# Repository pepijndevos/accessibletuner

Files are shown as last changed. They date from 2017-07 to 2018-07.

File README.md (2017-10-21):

# accessibletuner
Accessible Guitar Tuner

[Project page](https://hackaday.io/project/26255-accesible-guitar-tuner)

## Bountysource



Please get in touch if you want to help. I may be able to send you a PCB, put up additional bounties or make other arrangements.

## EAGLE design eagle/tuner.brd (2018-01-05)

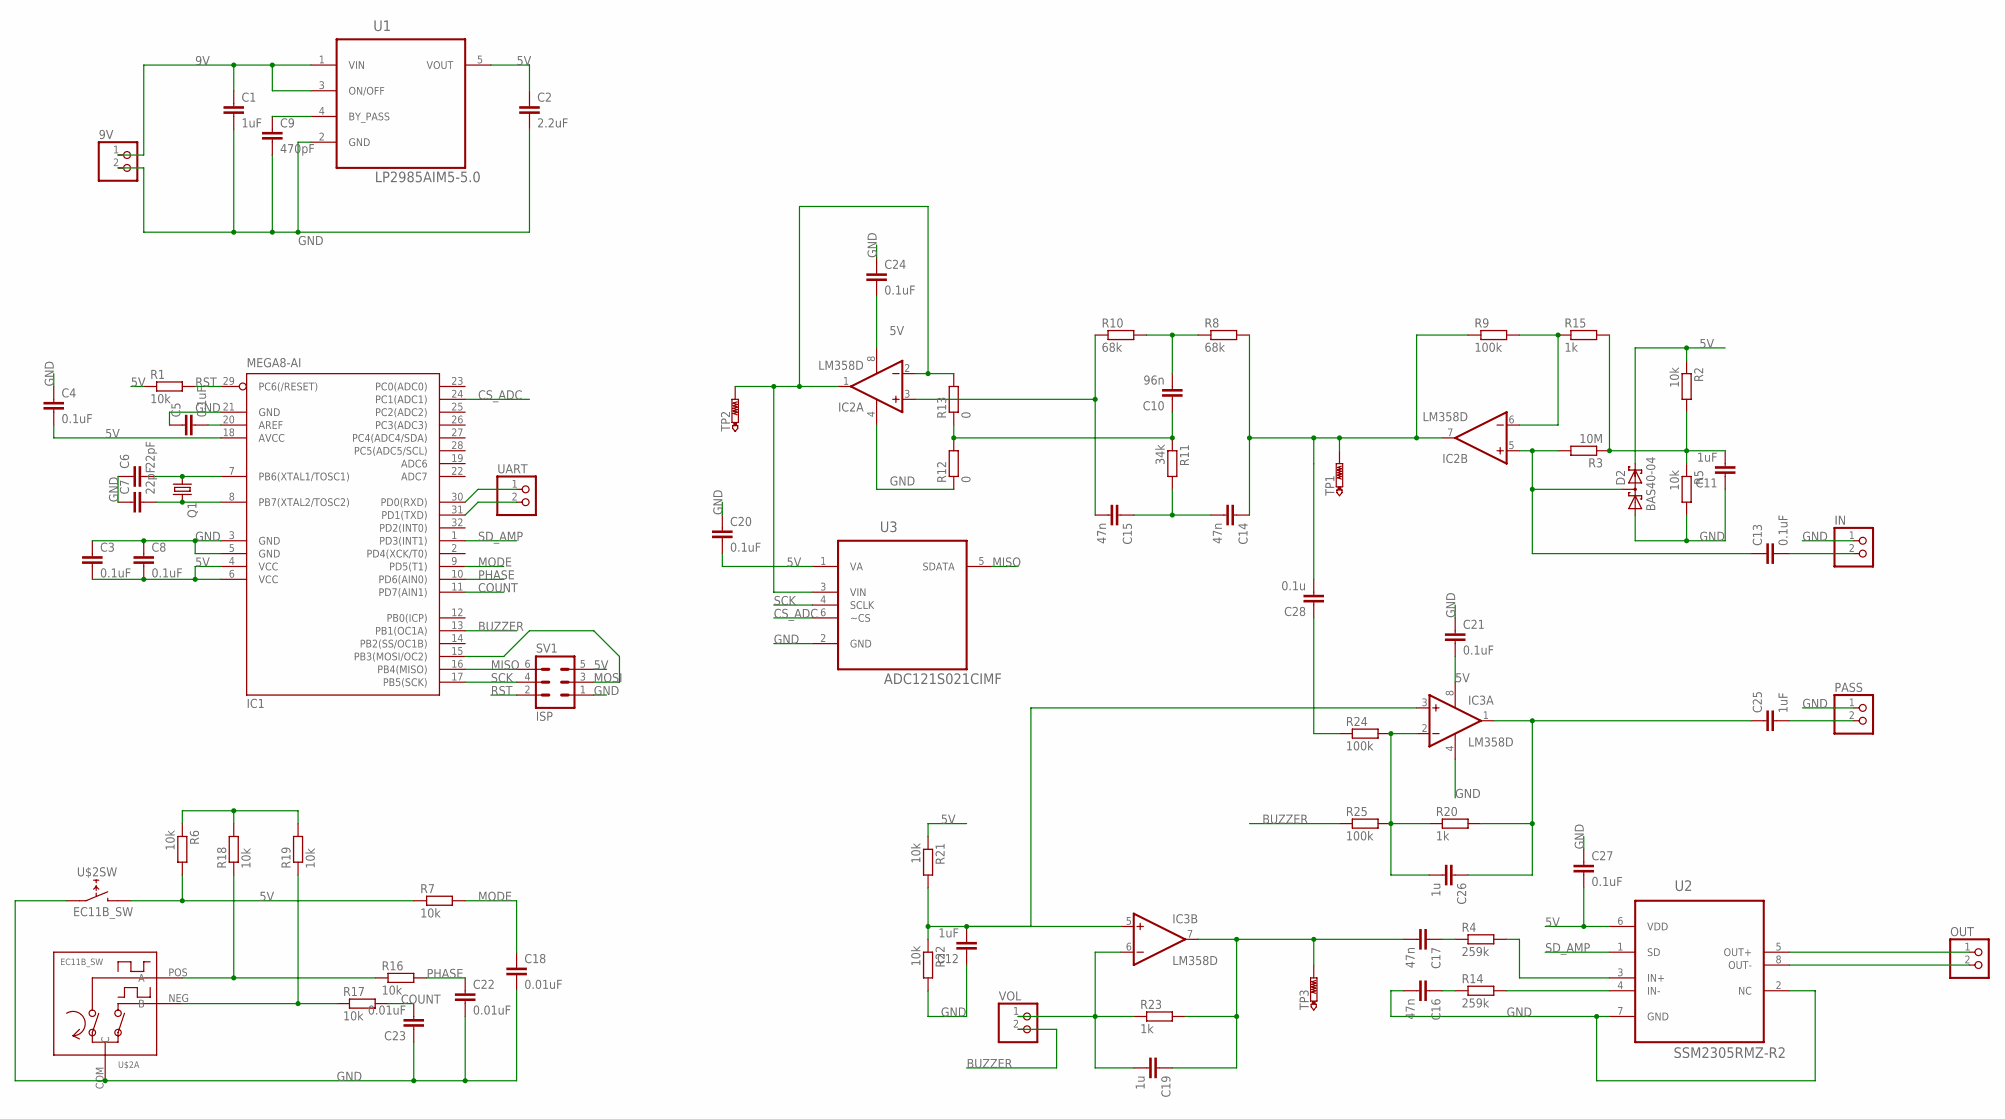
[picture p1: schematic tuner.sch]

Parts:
9V: PINHD-1X2; 1X02
C1, C11, C12, C25: 1uF; C0805
C2: 2.2uF; C0805
C3, C4, C5, C8, C13, C20, C21, C24, C27: 0.1uF; C0805
C6, C7: 22pF; C0805
C9: 470pF; C0805
C10: 96n; C0805
C14, C15, C16, C17: 47n; C0805
C18, C22, C23: 0.01uF; C0805
C19, C26: 1u; C0805
C28: 0.1u; C0805
D2: BAS40-04; SOT23
IC1: MEGA8-AI; TQFP32-08
IC2, IC3: LM358D; SO08
IN: PINHD-1X2; 1X02
OUT: PINHD-1X2; 1X02
PASS: PINHD-1X2; 1X02
Q1: CRYSTALHC49S; HC49/S
R1, R2, R5, R6, R7, R16, R17, R18, R19, R21, R22: 10k; M0805
R3: 10M; M0805
R4, R14: 259k; M0805
R8, R10: 68k; M0805
R9, R24, R25: 100k; M0805
R11: 34k; M0805
R12, R13: 0; M0805
R15, R20, R23: 1k; M0805
SV1: ISP; MA03-2
TP1, TP2, TP3: PTR1B1,27; B1,27
U1: LP2985AIM5-5.0; SOT95P284X119-5N
U2: SSM2305RMZ-R2; SOP65P490X110-8N
U3: ADC121S021CIMF; SOT95P284X122-6N
U$2: EC11B_SW; EC11B
UART: PINHD-1X2; 1X02
VOL: PINHD-1X2; 1X02

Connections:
5V: C2.1, C3.2, C4.2, C8.2, C20.2, C21.2, C24.2, C27.2, D2.2 (C2), IC1.4 (VCC), IC1.6 (VCC), IC1.18 (AVCC), IC2.8 (V+), IC3.8 (V+), R1.1, R2.1, R6.1, R18.2, R19.2, R21.1, SV1.5, U1.5 (VOUT), U2.6 (VDD), U3.1 (VA)
9V: 9V.1, C1.1, U1.1 (VIN), U1.3 (ON/OFF)
BUZZER: IC1.13 (PB1(OC1A)), R25.1, VOL.2
COUNT: C23.2, IC1.11 (PD7(AIN1)), R17.2
CS_ADC: IC1.24 (PC1(ADC1)), U3.6 (~CS)
FG: C10.1, R11.1, R12.2, R13.1
GND: 9V.2, C1.2, C2.2, C3.1, C4.1, C5.1, C6.1, C7.1, C8.1, C9.2, C11.1, C12.1, C16.2, C18.2, C20.1, C21.1, C22.2, C23.1, C24.1, C27.1, D2.1 (A1), IC1.3 (GND), IC1.5 (GND), IC1.21 (GND), IC2.4 (V-), IC3.4 (V-), IN.1, PASS.1, R5.2, R12.1, R22.2, SV1.1, U1.2 (GND), U2.2 (NC), U2.7 (GND), U3.2 (GND), U$2.COM (C), U$2.SW1 (D)
MISO: IC1.16 (PB4(MISO)), SV1.6, U3.5 (SDATA)
MODE: C18.1, IC1.9 (PD5(T1)), R7.2
MOSI: IC1.15 (PB3(MOSI/OC2)), SV1.3
unnamed: C28.1, R24.1
unnamed: C9.1, U1.4 (BY_PASS)
unnamed: C5.2, IC1.20 (AREF)
unnamed: C6.2, IC1.7 (PB6(XTAL1/TOSC1)), Q1.1
unnamed: C7.2, IC1.8 (PB7(XTAL2/TOSC2)), Q1.2
unnamed: C17.2, C19.1, IC3.7 (OUT), R23.2, TP3.TP
unnamed: C19.2, IC3.6 (-IN), R23.1, VOL.1
unnamed: C12.2, IC3.3 (+IN), IC3.5 (+IN), R21.2, R22.1
unnamed: OUT.1, U2.5 (OUT+)
unnamed: C14.1, C28.2, IC2.7 (OUT), R8.2, R9.1, TP1.TP
unnamed: OUT.2, U2.8 (OUT-)
unnamed: C13.2, IN.2
unnamed: IC2.6 (-IN), R9.2, R15.1
unnamed: R4.2, U2.3 (IN+)
unnamed: C25.2, PASS.2
unnamed: C13.1, D2.3 (C1A2), IC2.5 (+IN), R3.2
unnamed: C11.2, R2.2, R3.1, R5.1, R15.2
unnamed: C25.1, C26.1, IC3.1 (OUT), R20.2
unnamed: C14.2, C15.1, R11.2
unnamed: C15.2, IC2.3 (+IN), R10.1
unnamed: R14.2, U2.4 (IN-)
unnamed: R16.1, R18.1, U$2.POS (A)
unnamed: R17.1, R19.1, U$2.NEG (B)
unnamed: IC1.30 (PD0(RXD)), UART.1
unnamed: C10.2, R8.1, R10.2
unnamed: IC1.31 (PD1(TXD)), UART.2
unnamed: C16.1, R14.1
unnamed: IC2.1 (OUT), IC2.2 (-IN), R13.2, TP2.TP, U3.3 (VIN)
unnamed: C17.1, R4.1
unnamed: C26.2, IC3.2 (-IN), R20.1, R24.2, R25.2
unnamed: R6.2, R7.1, U$2.SW2 (E)
PHASE: C22.1, IC1.10 (PD6(AIN0)), R16.2
RST: IC1.29 (PC6(/RESET)), R1.2, SV1.2
SCK: IC1.17 (PB5(SCK)), SV1.4, U3.4 (SCLK)
SD_AMP: IC1.1 (PD3(INT1)), U2.1 (SD)

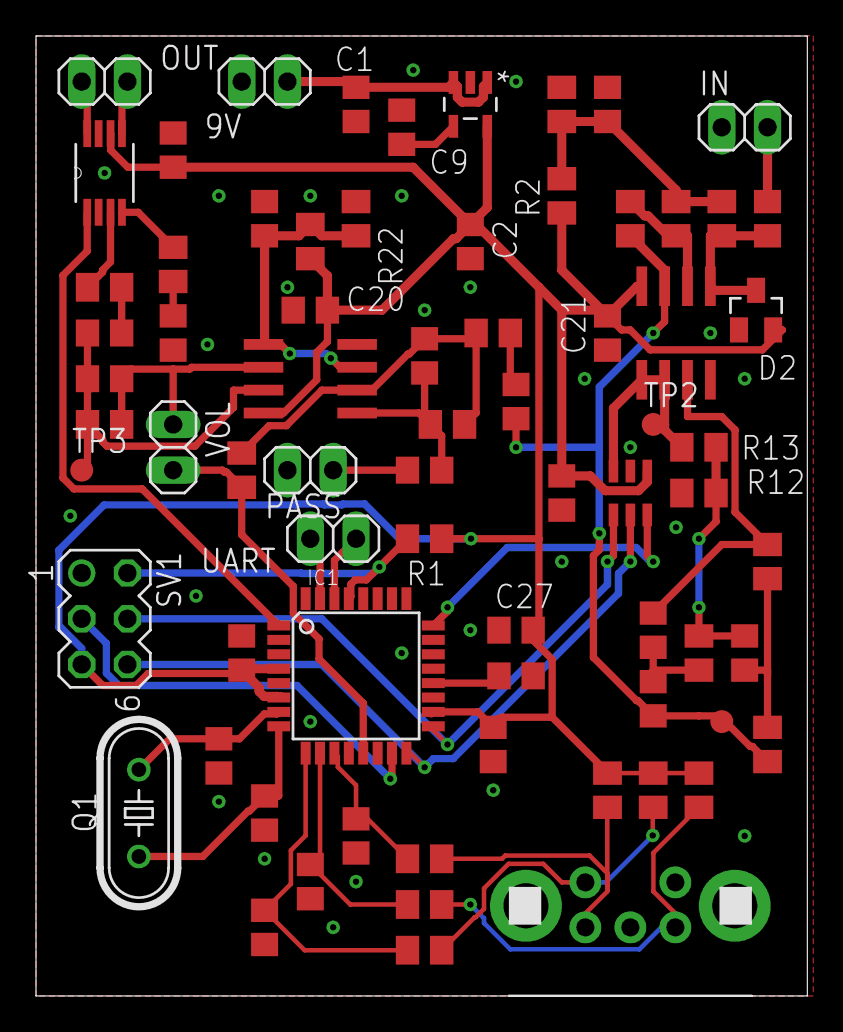
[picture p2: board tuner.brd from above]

Board: 2 copper layers, 42.8 x 53.3 mm, 72 parts (0 on the bottom side), 45 nets.

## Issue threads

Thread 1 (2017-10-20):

Seperate analog and digital circuitry

pepijndevos, 2017-10-20:
In the current PCB revision analog and digital ground and power supply are not really properly isolated. I added the inductor to AVCC of the AVR because the datasheet told me to, but the rest is a bit of a mess.

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

pepijndevos, 2017-11-27:
A new circuit was proposed by @brain4d, which is being implemented.

Closed 2017-11-27.

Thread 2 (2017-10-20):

Implement software band-pass filter

pepijndevos, 2017-10-20:
This will increase the reliability of tuning hopefully, but requires a lot of changes to the code.
The sampling frequency needs to be decreased to reasonable values to be able to construct reasonable filters.
The code also needs to be converted to using signed integers throughout.
Some work has been done in this area, but nothing that really works.

Ideally the filter is dynamically adjusted to the right frequency, but a lookup table is acceptable I think.

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

brain4d, 2017-10-24:
i'm really interested  in your  bounty. I have some experience in mixed-signal pcb design, and firmware development.
How can i discuss with you in detail?

pepijndevos, 2017-10-24:
Awesome! Shoot me an email at pepijndevos@gmail.com

brain4d, 2017-10-24:
i already sent you an email.

pepijndevos, 2018-02-22:
As of dbe5d09517160fcf41d7a1f8d89856c811fa1d5f this has been implemented by me. So instead I'll award the bounty to @ant0nisk for his work on the 3D printed case.

Closed 2018-02-22.

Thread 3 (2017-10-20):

Improve input stage

pepijndevos, 2017-10-20:
- [x] high input impedance
- [ ] automatic gain control
- [x] filter (50Hz) interference
- [x] stable

Closed 2018-02-08.

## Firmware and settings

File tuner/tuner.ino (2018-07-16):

#include <SPI.h>

#include "trig8.h"
#include "iir.h"
#include <limits.h>

#define SEMI 1.059463
#define CENT 1.0005777895

// Adjust to tune the tuner
#define ADCFREQ 1982.0
// scales to the range of sin8: 0-255
#define OMEGA (256/ADCFREQ)

#define E4 329.63
#define B3 246.94
#define G3 196.00
#define D3 146.83
#define A2 110.00
#define E2 82.41

#define BUZZER 9
#define EN_OUT 3
#define ADC_CS A1

// PORTB
#define SCROLL_MODE 5
#define SCROLL_PHASE 6
#define SCROLL_COUNTER 7

volatile unsigned long long counter = 0;
unsigned long sample_interval = 0;
unsigned long click_interval = 0;
int phase = 0;

const float strings[6] = {E2, A2, D3, G3, B3, E4};
int note_idx = 0;
bool standard_tuning = true;
float note = strings[0]*OMEGA;
IIR_filter bpf = iirpeak(strings[0]*2/ADCFREQ, 10*2/ADCFREQ);
IIR_filter lpf = {0, 0, 0, 0, 2, 4, 2, 3910, -1870};

void setup(){
  Serial.begin(250000);
  SPI.begin();
  
  pinMode(ADC_CS, OUTPUT);
  pinMode(BUZZER, OUTPUT);
  pinMode(EN_OUT, OUTPUT);
    // rotary encoder
  pinMode(SCROLL_MODE, INPUT);
  pinMode(SCROLL_PHASE, INPUT);
  pinMode(SCROLL_COUNTER, INPUT);

  PCICR = (1 << PCIE2);  //Enable PCI2 interupt
  PCMSK2 = (1 << PCINT21) | (1 << PCINT22) | (1 << PCINT23);  // Mask for encoder pins
      
  // Enable output A, B, fast PWM
  TCCR1A =  _BV(COM1A1) | _BV(WGM10);
  // No PWM prescaler
  TCCR1B = _BV(CS10) | _BV(WGM12);
  // Duty cycle
  OCR1A = 127;
  digitalWrite(EN_OUT, HIGH);
}

//https://www.circuitsathome.com/mcu/reading-rotary-encoder-on-arduino/
SIGNAL(PCINT2_vect) {
  const int8_t enc_states[] = {0,-1,1,0,1,0,0,-1,-1,0,0,1,0,1,-1,0};
  // 00 00 -> --
  // 00 01 -> CW
  // 00 10 -> CCW
  // 00 11 -> --
  // 01 00 -> CCW
  // 01 01 -> --
  // 01 10 -> --
  // 01 11 -> CW
  // 10 00 -> CW
  // 10 01 -> --
  // 10 10 -> --
  // 10 11 -> CCW
  // 11 00 -> --
  // 11 01 -> CCW
  // 11 10 -> CW
  // 11 11 -> --
  //const float enc_states[] = {1,1,1,1,1,1,1,1/SEMI,1,1,1,SEMI,1,1,1,1};
  static uint8_t old_AB = 0;

  old_AB <<= 2; //remember previous state
  old_AB |= (PIND >> 6) & 0x03; //add current state
  //note_idx *= enc_states[old_AB & 0x0f];
  note_idx += enc_states[old_AB & 0x0f];

  if(((PIND >> 5) & 0x01)==0) {
    standard_tuning = !standard_tuning;
    note_idx = 0;
  }

  float string_freq;
  if(standard_tuning) {
    string_freq = strings[(((note_idx/4) % 6) + 6) % 6];
  } else {
    string_freq = strings[0]*pow(SEMI, note_idx);
  }
  
  note = string_freq*OMEGA;
  IIR_filter bpf = iirpeak(string_freq*2/ADCFREQ, 10*2/ADCFREQ);
}

void loop() {
  while(micros()-sample_interval < 500 || micros() < sample_interval);
  sample_interval = micros();

  // Do this first to reduce jitter
  OCR1A = sin8(note*counter+phase);

  SPI.beginTransaction(SPISettings(F_CPU/2, MSBFIRST, SPI_MODE0));
  digitalWrite(ADC_CS, LOW);
  delayMicroseconds(1);
  int16_t val = (int16_t)SPI.transfer16(0) - (1<<11);
  digitalWrite(ADC_CS, HIGH);
  SPI.endTransaction();
    
  int16_t sine = (int16_t)sin8(note*counter)-(int16_t)127;

  int16_t fval = IIR2(&bpf, val);
  int16_t prod = fval*sine;
  int16_t lpval = IIR2(&lpf, prod);
  // timeout on clicker for anti-madness
  if(millis()-click_interval > 20) {
    click_interval = millis();
    phase = (lpval>0)*128;
  }

//if(counter % 64 == 0) {
//  Serial.print(((PIND >> 5) & 0x01)==0);
//  Serial.print("\t");
//  Serial.print(note_idx, DEC);
//  Serial.print("\t");
//  Serial.println(standard_tuning, DEC);
//  Serial.print("\t");
//  Serial.println(micros()-sample_interval, DEC);
//}

  counter++;
}

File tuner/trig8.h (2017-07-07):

#ifndef __INC_LIB8TION_TRIG_H
#define __INC_LIB8TION_TRIG_H

#define LIB8STATIC __attribute__ ((unused)) static

///@ingroup lib8tion

///@defgroup Trig Fast trig functions
/// Fast 8 and 16-bit approximations of sin(x) and cos(x).
///        Don't use these approximations for calculating the
///        trajectory of a rocket to Mars, but they're great
///        for art projects and LED displays.
///
///        On Arduino/AVR, the 16-bit approximation is more than
///        10X faster than floating point sin(x) and cos(x), while
/// the 8-bit approximation is more than 20X faster.
///@{

#if defined(__AVR__)
#define sin16 sin16_avr
#else
#define sin16 sin16_C
#endif

/// Fast 16-bit approximation of sin(x). This approximation never varies more than
/// 0.69% from the floating point value you'd get by doing
///
///     float s = sin(x) * 32767.0;
///
/// @param theta input angle from 0-65535
/// @returns sin of theta, value between -32767 to 32767.
LIB8STATIC int16_t sin16_avr( uint16_t theta )
{
    static const uint8_t data[] =
    { 0,         0,         49, 0, 6393%256,   6393/256, 48, 0,
      12539%256, 12539/256, 44, 0, 18204%256, 18204/256, 38, 0,
      23170%256, 23170/256, 31, 0, 27245%256, 27245/256, 23, 0,
      30273%256, 30273/256, 14, 0, 32137%256, 32137/256,  4 /*,0*/ };

    uint16_t offset = (theta & 0x3FFF);

    // AVR doesn't have a multi-bit shift instruction,
    // so if we say "offset >>= 3", gcc makes a tiny loop.
    // Inserting empty volatile statements between each
    // bit shift forces gcc to unroll the loop.
    offset >>= 1; // 0..8191
    asm volatile("");
    offset >>= 1; // 0..4095
    asm volatile("");
    offset >>= 1; // 0..2047

    if( theta & 0x4000 ) offset = 2047 - offset;

    uint8_t sectionX4;
    sectionX4 = offset / 256;
    sectionX4 *= 4;

    uint8_t m;

    union {
        uint16_t b;
        struct {
            uint8_t blo;
            uint8_t bhi;
        };
    } u;

    //in effect u.b = blo + (256 * bhi);
    u.blo = data[ sectionX4 ];
    u.bhi = data[ sectionX4 + 1];
    m     = data[ sectionX4 + 2];

    uint8_t secoffset8 = (uint8_t)(offset) / 2;

    uint16_t mx = m * secoffset8;

    int16_t  y  = mx + u.b;
    if( theta & 0x8000 ) y = -y;

    return y;
}

/// Fast 16-bit approximation of sin(x). This approximation never varies more than
/// 0.69% from the floating point value you'd get by doing
///
///     float s = sin(x) * 32767.0;
///
/// @param theta input angle from 0-65535
/// @returns sin of theta, value between -32767 to 32767.
LIB8STATIC int16_t sin16_C( uint16_t theta )
{
    static const uint16_t base[] =
    { 0, 6393, 12539, 18204, 23170, 27245, 30273, 32137 };
    static const uint8_t slope[] =
    { 49, 48, 44, 38, 31, 23, 14, 4 };

    uint16_t offset = (theta & 0x3FFF) >> 3; // 0..2047
    if( theta & 0x4000 ) offset = 2047 - offset;

    uint8_t section = offset / 256; // 0..7
    uint16_t b   = base[section];
    uint8_t  m   = slope[section];

    uint8_t secoffset8 = (uint8_t)(offset) / 2;

    uint16_t mx = m * secoffset8;
    int16_t  y  = mx + b;

    if( theta & 0x8000 ) y = -y;

    return y;
}


/// Fast 16-bit approximation of cos(x). This approximation never varies more than
/// 0.69% from the floating point value you'd get by doing
///
///     float s = cos(x) * 32767.0;
///
/// @param theta input angle from 0-65535
/// @returns sin of theta, value between -32767 to 32767.
LIB8STATIC int16_t cos16( uint16_t theta)
{
    return sin16( theta + 16384);
}

///////////////////////////////////////////////////////////////////////

// sin8 & cos8
//        Fast 8-bit approximations of sin(x) & cos(x).
//        Input angle is an unsigned int from 0-255.
//        Output is an unsigned int from 0 to 255.
//
//        This approximation can vary to to 2%
//        from the floating point value you'd get by doing
//          float s = (sin( x ) * 128.0) + 128;
//
//        Don't use this approximation for calculating the
//        "real" trigonometric calculations, but it's great
//        for art projects and LED displays.
//
//        On Arduino/AVR, this approximation is more than
//        20X faster than floating point sin(x) and cos(x)

#if defined(__AVR__) && !defined(LIB8_ATTINY)
#define sin8 sin8_avr
#else
#define sin8 sin8_C
#endif


const uint8_t b_m16_interleave[] = { 0, 49, 49, 41, 90, 27, 117, 10 };

/// Fast 8-bit approximation of sin(x). This approximation never varies more than
/// 2% from the floating point value you'd get by doing
///
///     float s = (sin(x) * 128.0) + 128;
///
/// @param theta input angle from 0-255
/// @returns sin of theta, value between 0 and 255
LIB8STATIC uint8_t  sin8_avr( uint8_t theta)
{
    uint8_t offset = theta;

    asm volatile(
                 "sbrc %[theta],6         \n\t"
                 "com  %[offset]           \n\t"
                 : [theta] "+r" (theta), [offset] "+r" (offset)
                 );

    offset &= 0x3F; // 0..63

    uint8_t secoffset  = offset & 0x0F; // 0..15
    if( theta & 0x40) secoffset++;

    uint8_t m16; uint8_t b;

    uint8_t section = offset >> 4; // 0..3
    uint8_t s2 = section * 2;

    const uint8_t* p = b_m16_interleave;
    p += s2;
    b   = *p;
    p++;
    m16 = *p;

    uint8_t mx;
    uint8_t xr1;
    asm volatile(
                 "mul %[m16],%[secoffset]   \n\t"
                 "mov %[mx],r0              \n\t"
                 "mov %[xr1],r1             \n\t"
                 "eor  r1, r1               \n\t"
                 "swap %[mx]                \n\t"
                 "andi %[mx],0x0F           \n\t"
                 "swap %[xr1]               \n\t"
                 "andi %[xr1], 0xF0         \n\t"
                 "or   %[mx], %[xr1]        \n\t"
                 : [mx] "=d" (mx), [xr1] "=d" (xr1)
                 : [m16] "d" (m16), [secoffset] "d" (secoffset)
                 );

    int8_t y = mx + b;
    if( theta & 0x80 ) y = -y;

    y += 128;

    return y;
}


/// Fast 8-bit approximation of sin(x). This approximation never varies more than
/// 2% from the floating point value you'd get by doing
///
///     float s = (sin(x) * 128.0) + 128;
///
/// @param theta input angle from 0-255
/// @returns sin of theta, value between 0 and 255
LIB8STATIC uint8_t sin8_C( uint8_t theta)
{
    uint8_t offset = theta;
    if( theta & 0x40 ) {
        offset = (uint8_t)255 - offset;
    }
    offset &= 0x3F; // 0..63

    uint8_t secoffset  = offset & 0x0F; // 0..15
    if( theta & 0x40) secoffset++;

    uint8_t section = offset >> 4; // 0..3
    uint8_t s2 = section * 2;
    const uint8_t* p = b_m16_interleave;
    p += s2;
    uint8_t b   =  *p;
    p++;
    uint8_t m16 =  *p;

    uint8_t mx = (m16 * secoffset) >> 4;

    int8_t y = mx + b;
    if( theta & 0x80 ) y = -y;

    y += 128;

    return y;
}
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

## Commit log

2017-07-10 initial lowpass filter with brokencoefficients
    [iir.h, tuner.ino]
2017-07-12 update simulation for second prototype
2017-07-13 improve volume and fix note selection on 328
    [tuner.ino]
2017-07-14 updated PCB
    [tuner.brd, tuner.sch]
2017-07-25 move pins around for PCB
2017-07-26 spi slave
2017-07-26 set SPI pins
2017-07-27 improved power supply noise rejection
2017-08-02 update schematic with agc and high-z input, D-class out
    [tuner.brd, tuner.sch]
2017-08-02 second revision
    [tuner.brd, tuner.sch]
2017-09-16 update for new pcb
2018-01-03 work on next revision PCB
    [tuner.brd, tuner.sch]
2018-01-04 do board layout
    [tuner.brd, tuner.sch]
2018-01-05 lemme smash
    [tuner.brd]
2018-02-18 get rid of timer interrupt
2018-02-18 fix those indices, idiot
    [tuner.ino]
2018-02-18 improve filter slightly. Output broke somewhere along the way
    [tuner.ino]
2018-02-18 commit actual working iir filter
2018-02-25 fix overflow and multiplication
    [tuner.ino]
